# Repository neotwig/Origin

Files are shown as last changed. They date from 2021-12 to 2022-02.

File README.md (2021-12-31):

# Origin

Origin is an open-source, customizable touchscreen HDMI switch with IR remote control.

This project was created by Ryan Black with coding by David Williams.  Documentation written by Ryan Black.

An annoucement video with a demonstration of a 25 port unit is [posted here](https://youtu.be/hIJCa2q1oEo).

Special thanks to Bob from [RetroRGB](https://www.retrorgb.com/) for his help in advertising the first and second generation units, allowing me to recoup some of my development costs.

## Features

* Can be built in 5, 9, 13 or 25 port configurations (17 or 21 ports are possible, but not yet implemented)
* 3.2" or 7" touchscreen display with brightness and auto-dimming / auto-off settings
* Infrared remote control, user-programmable to work with most any IR remote control
* User-configurable input names and color scheme
* Uses 1 to 6 HDMI switchboards internally.  Origin is designed to power off any switchboards not currently needed to conserve power.  Only 1 or 2 switchboards are powered at any given time.

## License

I am releasing the source code and build instructions under the MIT license.  You are free to use any of it however you would like.  If you profit from my work, please consider sending a little something my way since I did invest quite a bit of time and money into this project.

There is no warranty of any kind, and it is up to you to make sure you build and use the device SAFELY.  If you plug 25 consoles into a lightweight extension cord and burn down your house, that is on you!  If you don't know how to work with electronic devices and electricity safely, this project is not for you.  Please game responsibly.

## Limitations

* I am not selling these devices.  I have a few extras I may sell to recover some of my development costs, but once they're gone, they're gone.  Total parts cost is high and the build is time consuming, so I cannot make these at a price most people would be willing to pay.  Current cost for PARTS ONLY for a 3.2" 9 port model is $250, and a 7" 25 port model is $500.
* I am not providing support for these devices.  Sorry, I am very busy and don't have the time to provide free technical support.
* I am NOT an expert at any of this.  I know just enough to get this working but this is a hobby, not a career.  There are probably better ways to do the electronics, the coding, and the 3D modeling for the case.  I welcome any and all improvements to the project.
* As of this writing, the 3.2" display models support 5, 9, and 13 port configurations.  The 7" display models only support 25 port configurations.
* The HDMI switchboards used internally DO support auto-switching of devices, but Origin does NOT support this as a whole.  Auto-switching will occur within a 5 port switchboard, but not for the rest of Origin.  Example: Ports 6-10 on a 25 port model are on the same physical switch board.  If I am using device #6 and turn it off, and device #10 is powered on, the switchboard will auto-select device #10.  However, if I then turn on device #2 and turn off device #10, it will NOT switch to device #2 since that is a different switchboard.

## Feature Additions

At this point in time, I do not plan to add any more features.  There are other things I would like to see added, but I am leaving this to the community.  Some ideas include:
* Protections against the user selecting conflicting colors, such as black text on a black background
* Wi-Fi / Ethernet / Bluetooth connectivity
* Web interface and/or phone and tablet apps to control and configure Origin
* The ability to control power for connected systems, such that pressing the NES button turns on your NES console via a smart outlet
* Support for pictures instead of just text, so that the user can touch an image of a console
* Full-screen display of the selected input for easier reading from across a room, especially when changing inputs via remote control

I am not going to claim that the GUI is perfect, but I did invest extra time in making it as close as I could.  I am certainly open to improvements, but fair warning that I am picky about this.  For example, Nextion does not natively allow for centering of multi-line text on buttons.  It "centers" the text as a block, with all lines left-justified based on the longest line.  I find this to be inexcusable, so I wrote extra code to implement proper multi-line centering with hotspots instead.  This does make the code more complex, but I think the user interface looks substantially better as a result.

## Hardware Build Video

I've created a [build video](https://youtu.be/xENX4zxrqHY) explaining the process from beginning to end, excluding the 3D printing of the enclosure.  The video is for a 5 port model, but the process is nearly identical for any port configuration.  The video is 1 hour and 42 minutes long.  I sped up some of the more tedious and repetitive tasks to shorten it as much as I could.

When building a device, you'll need to place a FAT32 formatted Micro SD card in the standalone internal SD card reader (NOT the one on the Nextion display).  You can pre-populate it with one of the provided sample preference files if you want, but if one doesn't exist then the software will generate a new one for you.

Note that the pin definitions are specified in the file "libraries\Origin\OriginConfig.h", so you may want to reference that for hooking up the wiring.

The commercial HDMI switchboards I've used are all internally branded as "ASK Technology" models "HDSW0015M1_1V3" or "HDSW0015M1_1V4".  Other models may not work, or may require significant modifications to the board, wiring, code, or enclosure design.

## Software Build Instructions

Requirements
* [Arduino IDE](https://www.arduino.cc/en/software) (developed with version 1.8.13)
* [Nextion Editor](https://nextion.tech/nextion-editor/) (developed with version 1.63.3)

Place the contents of the "libaries" folder inside your Arduino libraries folder.  On Windows, this is in your Documents library under Arduino\libraries.

Edit the file "OriginConfig.h" to specify the number of connected HDMI switches.  A 9 port Origin uses 2 switchboards, so set NUM_SWITCHES = 2.  A 25 port Origin uses 6 physical switchboards, so set NUM_SWITCHES = 6.

Connect the Arduino Mega 2650 to your computer via USB.  Select the Arduino Mega 2560 board in the Tools menu under the Board submenu, and choose the port your Arduino is connected to.  If you've already removed the Arduino fuse (per the build instructions) and/or connected the Arduino to other Origin components such as HDMI switchboards and a touchscreen, you must supply external power to the Origin box in order to program the Arduino.

The Nextion display is programmed with a Micro SD card.  If you have the same Nextion display model that I used, you can simply copy the appropriate .tft file to a FAT32 formatted Micro SD card.  If you are using a different model, you have to export a TFT file using the Nextion Editor software.  To program the Nextion, first turn Origin off.  Insert the Micro SD card into the slot on the bottom of Origin.  Then power Origin on, and you should see the display install the new code.  Once it reports that it is complete, you may power off Origin and remove the Micro SD card.

## History

This is the third generation of the Origin HDMI switch, but the first two were not publicly released.  I developed the first two versions entirely by myself, which proved to be quite a challenge!  I selected the name "Origin" due to the purpose of the device.  My goal was to have a single point to select any video game console or multimedia device, rather than having to change inputs on the TV and also on a variety of switchboxes.  Hence, the "Origin" of all video signals in your entertainment setup would be this switchbox, and your TV's input selection never has to change.

I started by making a 17 port version based on HDMI 1.3b switches.  It was a learning project, to push the limits of my electronics, coding, and 3D modeling skills.  All of these things were purely hobbies that I learned by watching YouTube videos, reading documentation and experimenting on sacrificial electronics.  I originally only made one Origin device for my personal use.  After successful completion of the project, I decided to make and sell two more.  Unfortunately they were expensive to make, time consuming to build, and would not be feasible to sell for profit.

The second generation was also a 17 port version, and it was based on HDMI 1.4 switches.  The goal of the second version was to reduce the cost of materials and possibly produce small batches for sale.  Unfortunately the cheaper components led to compatibility issues with some systems such as Hi-Def NES and UltraHDMI N64 modded consoles.  The design of the cheaper HDMI switches allowed for direct control over input selection which was an advantage over both the first and third iterations of Origin, but the compatibility issues and lack of support for HDMI 2.0 made it less desirable.  Seven of these models were made and sold, but despite the cheaper materials they were still not profitable, partly due to the compatibility issues.

I set forth to develop a third generation Origin device.  By this time my game console collection had grown beyond the 17 ports of the original version, and HDMI 2.0 support was becoming more important.  Since the first two models were not profitable, and the parts to support HDMI 2.0 were even more expensive, I decided to throw profitability out the window and simply develop the best switch possible, regardless of cost, with the intention of open-sourcing the device rather than trying to sell it.  I purchased and tested numerous HDMI switches and cables.  I had to tear each HDMI switch apart to determine how readily it could be controlled by an Arduino.  I focused on models that are widely available since development takes a long time and there's no point in open-sourcing something if the hardware is discontinued by the time the project is complete.  Eventually I landed on a set of parts that provided the best compatibility, modability, and availability.  The list of parts is included in this release, though availability may change as time goes on.

I recruited my friend David to help set with the coding part of the new Origin project.  Unlike myself, he does coding professionally and has a much better understanding of how to arrange things.  Don't blame him for any mess you might find in the code though, as I did contribute a fair amount with my duct tape and bubblegum "just get it done" coding skills.  :)

Traditional Arduino-compatible touchscreen displays are very slow, and I knew that something better would be needed for anything larger than 17 ports.  I landed on a much more expensive, but much more powerful Nextion display.  These displays have their own processor and their own programming environment and language.  It presented another learning curve, but I think it was the right choice.  A Nextion expert could significantly improve the way it's implemented, but David and I came up with a reasonably fast and user-friendly interface.  It's our first Nextion project, so improvements are welcome!

This project has taken approximately 3 years to complete as a hobby project, not a full-time endeavor.  It has been an expensive undertaking, with the need for 3D printing hardware, filament, soldering tools and supplies, and a fair amount of HDMI switches which were sacrificed to find the best configuration.

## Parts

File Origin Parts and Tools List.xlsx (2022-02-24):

Type | Description with link as of 12/2021 | Approx. cost as of 12/2021 | Notes
Part | Arduino MEGA R3 Board ATmega 2560 (https://www.amazon.com/gp/product/B01H4ZLZLQ) | $18
Part | ViewHD 5 port HDMI 2.0 5x1 Switch UHD5X1 (https://www.amazon.com/gp/product/B07J6GJ448) | $33 each
Part | AwakeLion 5 port HDMI 2.0 Switch (https://www.amazon.com/Switch-Awakelion-Premium-Switcher-Support/dp/B06WV5YJ6H) | $40 each
Part | HDMI Cable 4K Ultra HD 1 Foot (3 Pack) (https://www.amazon.com/gp/product/B074HQQWD7) | $15 for 3 | need x-1 where x is number of switch boards
Part | HDMI Cable 4K Ultra HD 1 Foot (10 Pack) (https://www.amazon.com/gp/product/B074HGW2FC) | $25 for 10 | need x-1 where x is number of switch boards
Part | Nextion NX4024T032 Display - 3.2" (https://www.amazon.com/dp/B08535GC8J) | $37 | CASE IS NOT NEEDED, but Amazon is out of stock of just the display as of 2/23/22
Part | Nextion NX8048K070 Display - 7" (https://www.amazon.com/gp/product/B079177F98) | $113
Part | AC/DC Wall Mount Adapter 5V 20W (https://www.digikey.com/en/products/detail/cui-inc/SWI25-5-N-P5/7070092) | $18 + shipping
Part | IR Receiver TSOP34438 (https://www.digikey.com/en/products/detail/vishay-semiconductor-opto-division/TSOP34438/4074442) | $1.50 + shipping | currently out of stock, untested possible replacement TSOP34438SS1F
Part | 3.3V-5V 4 Channels Logic Level Converter (https://www.amazon.com/gp/product/B074M8TM81) | $9 for 10 | need 1 per switch board
Part | Micro SD Card Reader (https://www.amazon.com/HiLetgo-Adater-Interface-Conversion-Arduino/dp/B07BJ2P6X6) | $7 for 5 | need 1
Part | 5.5mm x 2.1mm DC Power Jack Panel Mount (https://www.amazon.com/gp/product/B073TS9H3S) | $9 for 20 | need 1
Part | SPST Snap in Mini Boat Rocker Switch (https://www.amazon.com/gp/product/B018FHB0H6) | $6 for 12 | need 1
Part | BusBoard (https://www.amazon.com/gp/product/B00PX52C7Q) | $10 for 8 | need 1
Part | 24 AWG Gauge Solid Hook Up Wire Kit (https://www.ebay.com/itm/322071452367) | $34 for 25 feet | need approximately 2 ft per switch board
Part | Heatshrink Tubing (https://www.amazon.com/gp/product/B073R69KNB) | $9 for a large pack | need only a tiny amount
Part | Rubber Bumpers Self Adhesive Large (https://www.amazon.com/gp/product/B01MR94CHS) | $11 for 20 | need 4
Part | Chemtronics Desoldering Braid (50 ft) Chem-Wik (https://www.amazon.com/gp/product/B0019V5MAC) | $20 for 50 ft | need only a few inches
Part | Steel Phillips Rounded Head Thread-Forming Screws for Plastic #4, 1/4" - McMaster-Carr Part 90380A106 (https://www.mcmaster.com/thread-forming-for-plastic/for-use-in~plastic/steel-phillips-rounded-head-thread-forming-screws-for-plastic/) | $9 + shipping for 100 | need qty 2 per switch board, qty 4 for 7" screen
Part | Steel Phillips Rounded Head Thread-Forming Screws for Plastic #4 - 3/8" - McMaster-Carr Part 90380A108 (https://www.mcmaster.com/thread-forming-for-plastic/for-use-in~plastic/steel-phillips-rounded-head-thread-forming-screws-for-plastic/) | $9 + shipping for 100 | need qty 6 for bottom, 4 for front panel, 2 for Arduino, 2 for power dist board
Part | HATCHBOX ABS 3D Printer Filament 1.75 mm Black (https://www.amazon.com/HATCHBOX-3D-Filament-Dimensional-Accuracy/dp/B00J0H8EWA) | $22 per spool | can make approx 3 total cases per spool
Part | HATCHBOX ABS 3D Printer Filament 1.75 mm White (https://www.amazon.com/HATCHBOX-3D-Filament-Dimensional-Accuracy/dp/B00J0H6NNM) | $22 per spool | need fairly negligible amount
Part | HATCHBOX ABS 3D Printer Filament 1.75 mm Green (https://www.amazon.com/HATCHBOX-3D-Filament-Dimensional-Accuracy/dp/B00J0HC4QC) | $22 per spool | need fairly negligible amount
Part | HATCHBOX ABS 3D Printer Filament 1.75 mm Red (https://www.amazon.com/HATCHBOX-3D-Filament-Dimensional-Accuracy/dp/B00J0HB1YI) | $23 per spool | need fairly negligible amount
Tool | Hakko FX888D Soldering Station (https://www.amazon.com/gp/product/B00C2BHTBI) | $145
Tool | Hakko FR301-03/P Desoldering Tool (https://www.amazon.com/American-HAKKO-Products-FR301-03-Desoldering/dp/B07BFVFMS9) | $269
Tool | Hakko 599B-02 Wire-type soldering iron tip cleaner (https://www.amazon.com/gp/product/B00FZPGDLA) | $11
Tool | Hakko CHP-170 Micro Cutter (https://www.amazon.com/gp/product/B00FZPDG1K) | $8
Tool | Mini Heat Gun (https://www.amazon.com/gp/product/B073RK2M2Y) | $13
Tool | Quick 861DW Hot Air Rework Station (https://www.amazon.com/Quick-861DW-Digital-Station-Display/dp/B00EID23J6) | $312
Tool | Xcelite NN7776VN Long Needle Nose Plier (https://www.amazon.com/Xcelite-NN7776VN-Long-Nose-Plier/dp/B074NKR8PT) | $21
Tool | Prusa i3 MK3S+ 3D Printer (https://www.prusa3d.com/product/original-prusa-i3-mk3s-3d-printer-5/) | $1039
Tool | Prusa i3 MMU2S upgrade kit (https://www.prusa3d.com/product/original-prusa-i3-mmu2s-upgrade-kit-for-mk2-5-mk3s-org/) | $299

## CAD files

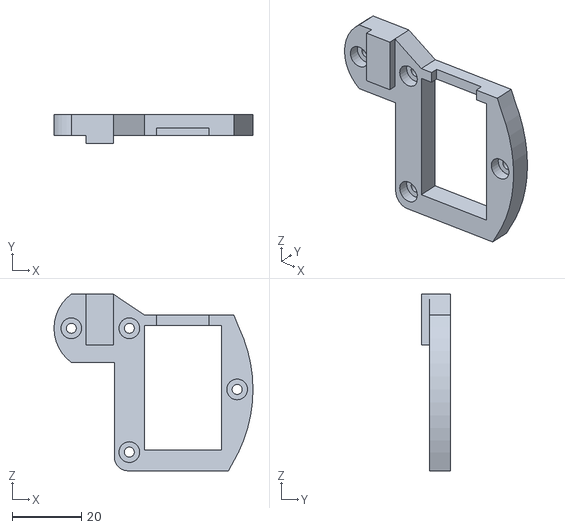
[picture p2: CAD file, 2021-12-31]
Enclosure Design/3.2 inch display/front bracket.stl
57.5 x 8.30 x 51.0

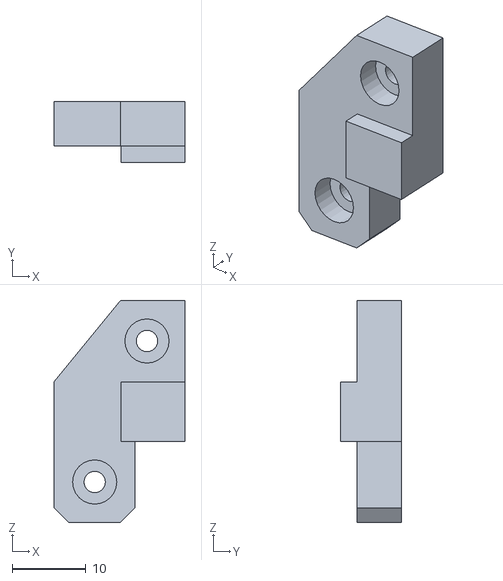
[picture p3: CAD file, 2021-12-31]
Enclosure Design/7.0 inch display/IR cover plate.stl
17.7 x 8.30 x 30.2

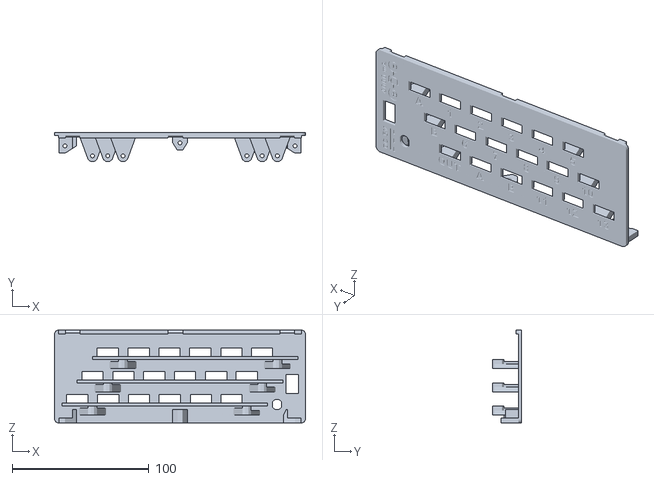
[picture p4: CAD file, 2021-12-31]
Enclosure Design/3.2 inch display/back 3 swx black.stl
183.7 x 21.4 x 68.0

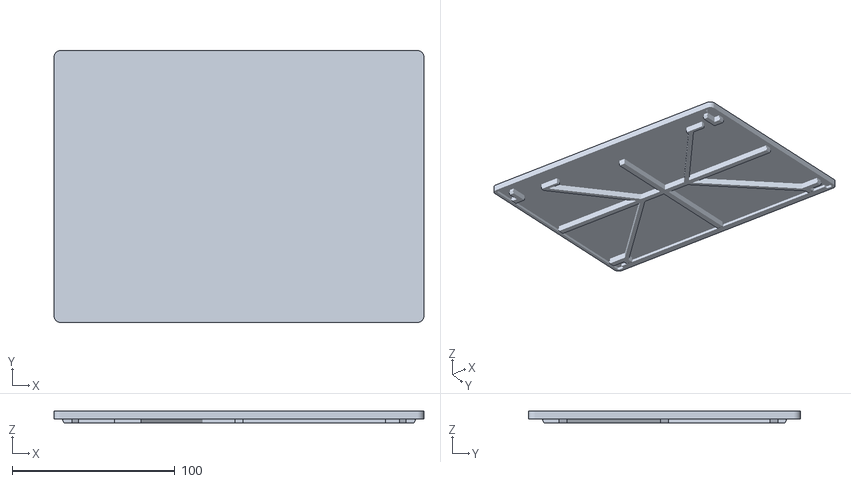
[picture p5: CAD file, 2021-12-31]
Enclosure Design/7.0 inch display/top panel.stl
227.0 x 166.7 x 7.50

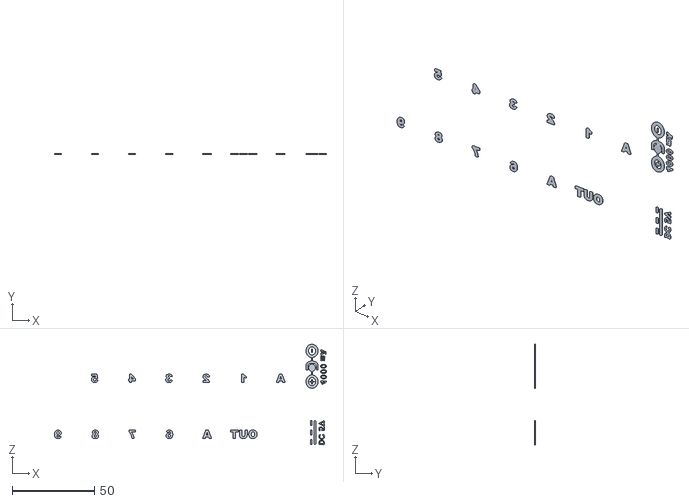
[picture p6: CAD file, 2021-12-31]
Enclosure Design/3.2 inch display/back 2 swx white.stl
165.1 x 0.653 x 61.1

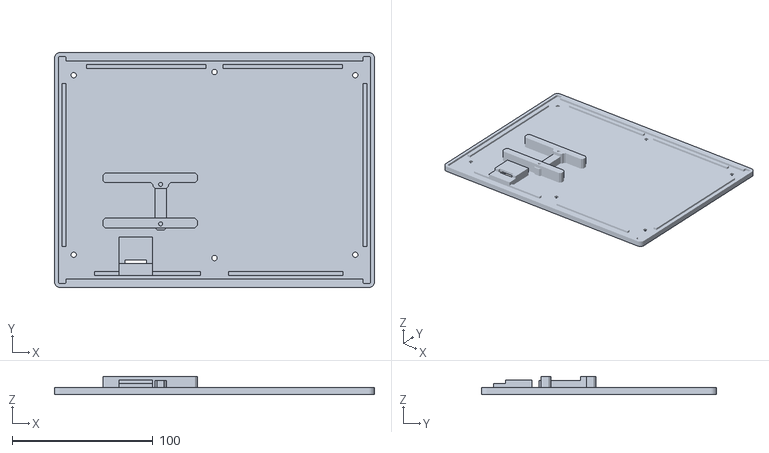
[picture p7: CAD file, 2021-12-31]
Enclosure Design/7.0 inch display/bottom panel.stl
227.0 x 166.7 x 13.0

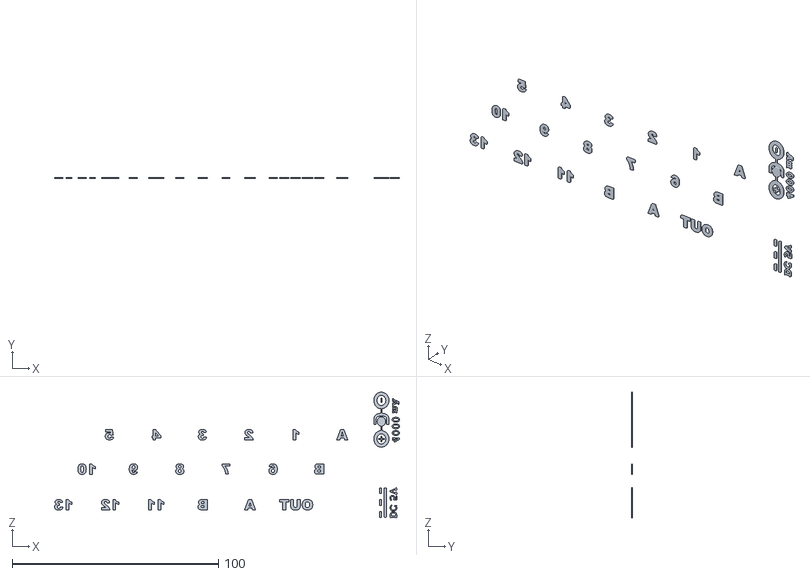
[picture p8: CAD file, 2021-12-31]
Enclosure Design/3.2 inch display/back 3 swx white.stl
167.3 x 0.655 x 61.1

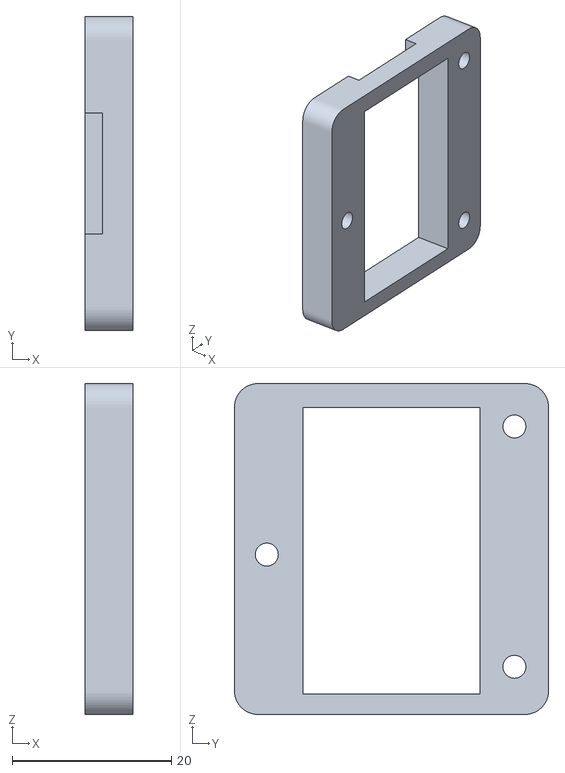
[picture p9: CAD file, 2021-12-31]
Enclosure Design/7.0 inch display/SD card cover plate.stl
6.05 x 39.5 x 41.6

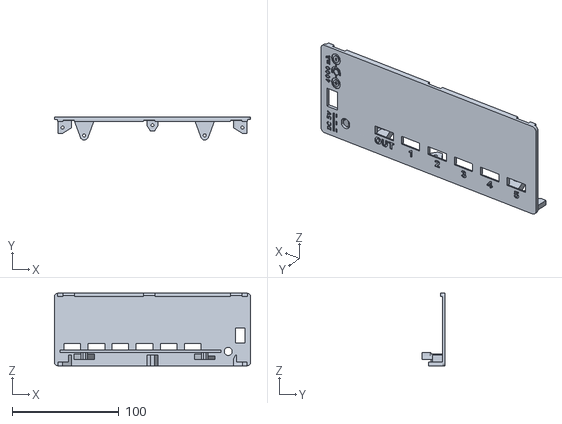
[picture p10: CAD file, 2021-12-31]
Enclosure Design/3.2 inch display/back 1 swx black.stl
183.7 x 21.4 x 68.0

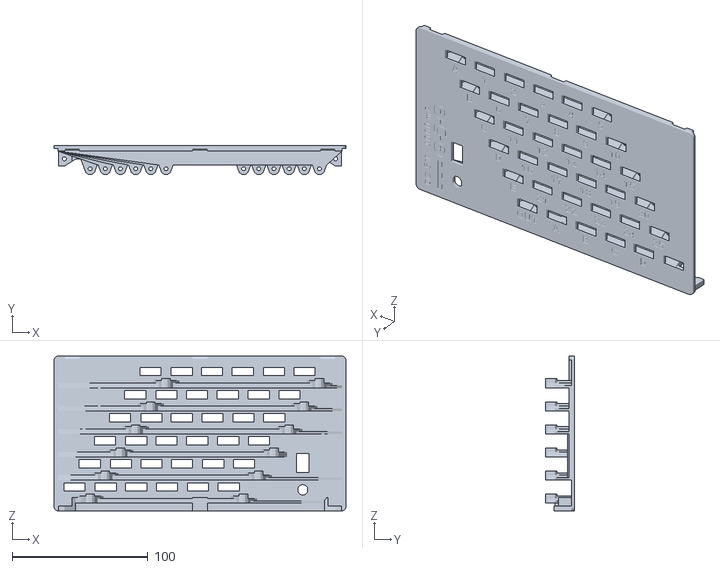
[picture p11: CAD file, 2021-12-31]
Enclosure Design/7.0 inch display/back panel black.stl
215.0 x 21.4 x 114.0

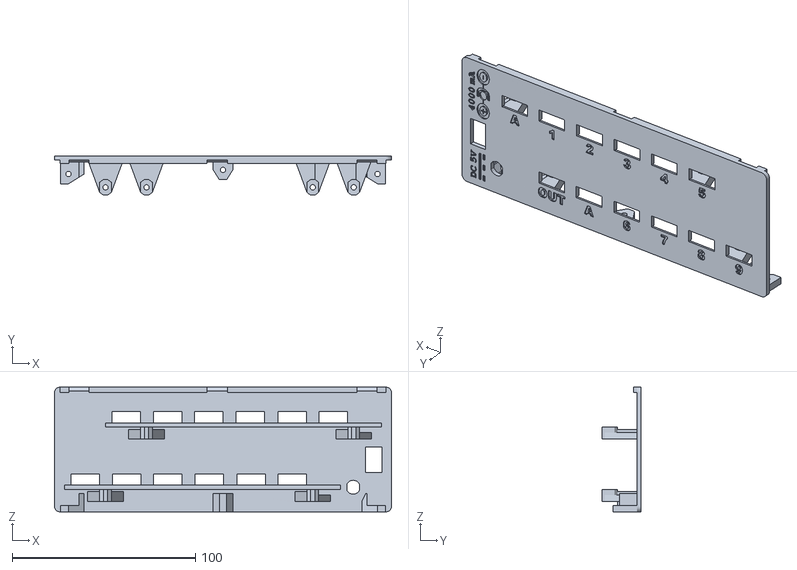
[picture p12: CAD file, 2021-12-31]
Enclosure Design/3.2 inch display/back 2 swx black.stl
183.7 x 21.4 x 68.0

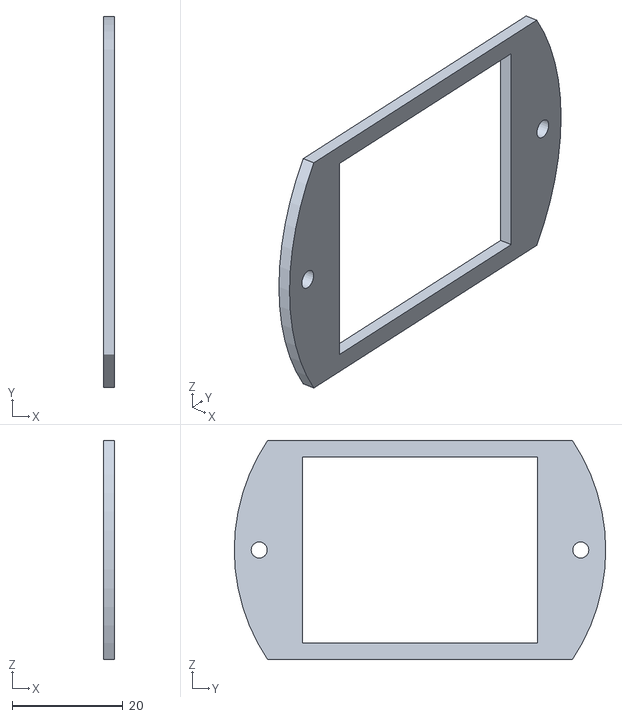
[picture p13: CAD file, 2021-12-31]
Enclosure Design/7.0 inch display/power board cover plate.stl
2.05 x 67.0 x 39.5

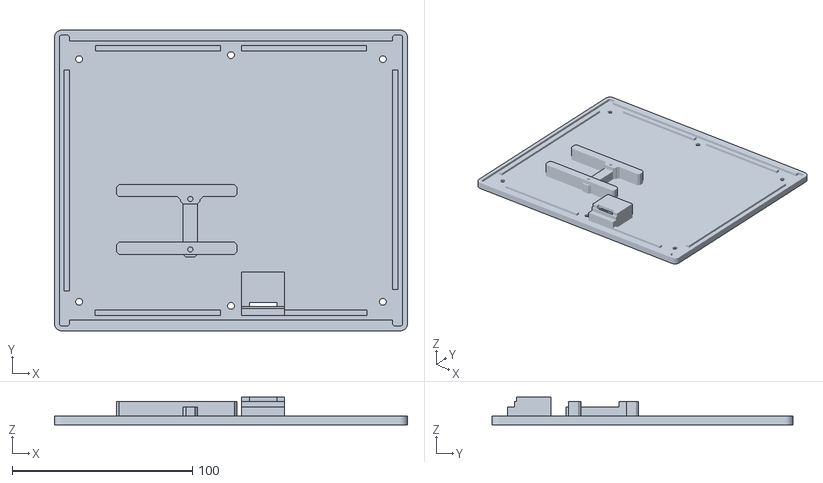
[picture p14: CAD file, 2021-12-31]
Enclosure Design/3.2 inch display/bottom panel.stl
195.8 x 166.7 x 15.4

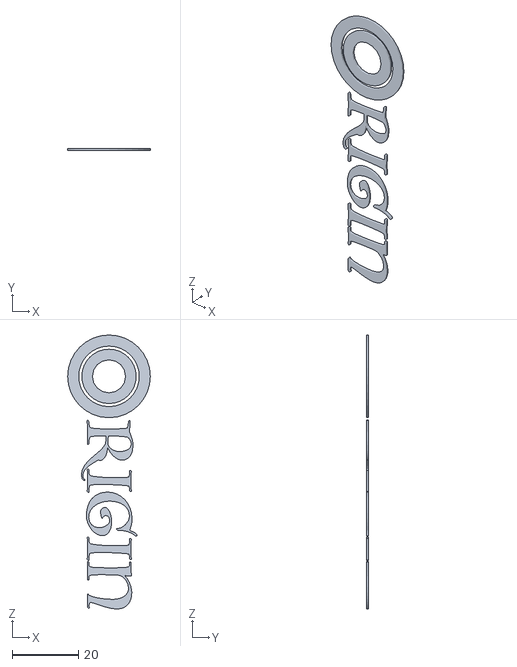
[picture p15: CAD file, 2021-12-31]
Enclosure Design/7.0 inch display/front panel red.stl
25.0 x 0.65 x 82.7

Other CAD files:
Enclosure Design/3.2 inch display/front white.stl
Enclosure Design/7.0 inch display/back panel white.stl
Enclosure Design/3.2 inch display/top panel.stl
Enclosure Design/7.0 inch display/front panel black.stl
Enclosure Design/3.2 inch display/back 1 swx white.stl
Enclosure Design/3.2 inch display/front black.stl
Enclosure Design/3.2 inch display/front green.stl
Enclosure Design/3.2 inch display/front red.stl
Enclosure Design/3.2 inch display/left panel.stl
Enclosure Design/3.2 inch display/right bracket.stl
Enclosure Design/3.2 inch display/right panel.stl
Enclosure Design/3.2 inch display/whole case 1 swx.skp
Enclosure Design/7.0 inch display/left panel.stl
Enclosure Design/7.0 inch display/right panel.stl

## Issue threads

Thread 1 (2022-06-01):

Fifth contact on switch PCB

sargunv, 2022-06-01:
Hi, I’m working on modding the same commercial HDMI switch you used for this project, the HDSW0015M1_1V4. Like you, I found the five pads on the PCB, two of which are wired to the buttons and the next two ground and 3.3V.

Unfortunately, I haven’t been able to figure out what the fifth pad in that row is for. Have you found what it’s used for?

My project is to build a mod that allows me to control the HDSW0015M1_1V4 over a serial connection, very similar to your Origin but without the extra switches and without the touch screen, just serial control for automation.

neotwig, 2022-06-01:
I never figured out what it was for, but I didn't need it for my project. I just used that connection for additional physical support of the level converter, but it isn't connected to the Arduino. If you're able to identify what it does, please share.

sargunv, 2022-06-01:
Last night I did use a multimeter to find it connects to the big IC in the middle just like the others, specifically the eighth pin from the left on the side facing the buttons.

Multimeter shows 0V on that pin whatever I do. Perhaps an input of some kind?

Next step would be removing the heat sink to try to see what that IC is and find the datasheet to identify the pins.

I also don't need this pad for my project, but am curious what it's for if they went to the trouble of creating an easy access pad for it. I'm also just a hobbyist, learning as I go with this project 🤷‍♂️

sargunv, 2022-06-01:
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

sargunv, 2022-06-04:
I can't find any pins on the datasheet for direct input switching, that functionality must only be exposed directly to the included microcontroller.

However, we _should_ be able to implement direct input switching anyway. Since the remote has input buttons 1-5 as well as direct on/off buttons, replacing the IR receiver with our own microcontroller should give us to ability to tell it to do those same things.

I haven't looked too deeply into doing this yet, but I did take a look at the voltages on that line and found it idles high, so I think we'd need to disconnect the actual IR receiver to properly simulate the signal from its pads. Going to attempt it once I've finished my prototype with just the straightforward I/O (the test pads and LEDs, like your project).

sargunv, 2022-06-04:
Full pinout here might be useful to you or anyone who comes across this thread.

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

sargunv, 2022-06-04:
Confirmed I can fake the IR commands from my Arduino Pro Mini. See the example code below.

I used [this tester](https://www.amazon.com/gp/product/B08K3BGKXC/) to grab the NEC signal codes, then [IrScrutinizer](https://github.com/bengtmartensson/IrScrutinizer) to get the unmodulated sequence, and finally the [Infrared4Arduino](https://github.com/bengtmartensson/Infrared4Arduino) library to send the sequence to the board.

```c++
#include <Nec1Renderer.h>
#include <IrSenderNonMod.h>

// pin connected to the leftmost pad that used to have the IR receiver
const int pinNec = 2;

// pin connected to the power LED
const int pinIdle = 8;

// generated with IrScrutinizer
// NEC encoding, device=1, function=31
const microseconds_t offData[] = {
  9024,4512,564,1692,564,564,564,564,564,564,564,564,564,564,564,564,564,564,564,
  564,564,1692,564,1692,564,1692,564,1692,564,1692,564,1692,564,1692,564,1692,564,
  1692,564,1692,564,1692,564,1692,564,564,564,564,564,564,564,564,564,564,564,564,
  564,564,564,564,564,1692,564,1692,564,1692,564,39756
};
const IrSequence offSeq(offData, sizeof(offData) / sizeof(microseconds_t));

// generated with IrScrutinizer
// NEC encoding, device=1, function=92
const microseconds_t onData[] = {
  9024,4512,564,1692,564,564,564,564,564,564,564,564,564,564,564,564,564,564,564,
  564,564,1692,564,1692,564,1692,564,1692,564,1692,564,1692,564,1692,564,564,564,
  564,564,1692,564,1692,564,1692,564,564,564,1692,564,564,564,1692,564,1692,564,
  564,564,564,564,564,564,1692,564,564,564,1692,564,39756
};
const IrSequence onSeq(onData, sizeof(onData) / sizeof(microseconds_t));

const IrSenderNonMod sender(pinNec, true);

void setup() {
  pinMode(pinNec, OUTPUT);
  pinMode(pinIdle, INPUT);
}

void loop() {
  auto idleVal = !digitalRead(pinIdle);

  if (idleVal) {
    sender.sendNonModulated(onSeq);
  } else {
    sender.sendNonModulated(offSeq);
  }

  delay(1000);
}
```

Here's the full list of the remote's functions I got from my tester. Device = 1 for all of them.

```
off -> 31
on -> 92
input 1 -> 27
input 2 -> 30
input 3 -> 13
input 4 -> 18
input 5 -> 16
next input -> 12
prev input -> 5
```

With this, I prob won't even bother hooking up the button on my final prototype; faking the IR signal does it all.

neotwig, 2022-06-06:
That is really awesome work, and thanks for the detailed explanation!  I bet this could be used to simplify the build for Origin and probably speed up input switching as well.

sargunv, 2022-06-07:
Glad it's helpful!

I managed to get the IR signal code to be much, much simpler using [a different IR library](https://github.com/Arduino-IRremote/Arduino-IRremote) and its `USE_NO_SEND_PWM` build flag.

https://github.com/sargunv/hdmi-switch-controller/blob/5250a682ed24b1df7fe1f89b9b76943275b6d30e/src/main.cpp

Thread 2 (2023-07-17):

Have you heard of anyone getting this to work with other revisions of the HDMI boards.

Slovlis, 2023-07-17:
I was super impressed with this project and had been wanting to try it for a while. Unfortunately, when I purchased the Awakelion HDMI switch from the parts list it's a different hardware revision. Still by ASK Technology, but version HDSW0032M1_1v0.
It does have the through holes to solder the headers for 3.3v and ground but when I probed the others it doesn't look like any go to the power and input switches. Just curious if you had heard of anyone using one of the other revisions, or do you think I could tap into the switches directly with some additional wiring from the level converter?
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

neotwig, 2023-07-17:
Ah, that's a bummer!  I was unaware that they have changed the boards internally.  It should be possible to wire the level converter directly to the appropriate leg of the power and switch input buttons.  Provided there aren't any other major changes I would think that should work without too much trouble.  You might not have as convenient of a place to mount the level converter PCB, but functionally it should be the same.

However, before you go to the trouble of mapping that all out, I would suggest just hooking two of these switches up together externally (in their original cases without modification) with a jumper HDMI cable going from the output of one to an input of another, and try a few different devices on various HDMI ports.  Particularly focus on ones on the second switch in the chain, to make sure that the HDMI signal travels through both switches to your TV without causing problems.  Ports RX4 and RX3 on your first pic are the most likely to have issues since they go through another chip, so be sure to test the "worst case scenario" of a device connected to RX4 on one switch with the output of that switch going to RX4 of the second switch before going to your TV.  I did find a few switches and cables that wouldn't properly transmit the signal, and if they can't do it on their own then there isn't any point in wiring them up.  If it doesn't work, try different cables first before swapping switch boards.  Thicker cables tend to work better between switches and between the last switch and the TV.

sargunv, 2024-05-16:
It's a different approach, but [my similar project](https://github.com/sargunv/hdmi-switch-controller) replaces the IR receiver and sends signals over that line simulating the IR codes to trigger the various inputs. The new board might have new IR codes, not sure, but the general strategy should still work.

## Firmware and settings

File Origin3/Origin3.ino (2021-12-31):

//////////////////////////////////////////////////////////////////////////////////////////////////////
//////////////////////   Origin 5, 9, 13, 17, 21, or 25 port HDMI 2.0 Switch   ///////////////////////
//////////////////////////////////////////////////////////////////////////////////////////////////////

#include <Arduino.h>
#include <OriginConfig.h>
#include <Origin.h>
#include <SPI.h>       // SPI = Serial Peripheral Interface.  Required for SD cards, among other things.
#include <SD.h>        // SD card reader
#include <Nextion.h>   // Nextion Display
#include <NextionHelper.h>
#include <SwitchBoard.h>

//////////////////////////////////////////////////////////////////////////////////////////////////////
// NOTE: NexHardware.h has default timeout values of 100 ms.  These need to be extended to allow some
// operations to complete without errors.  3000 ms is recommended.  Lower values would probably work
// but have not been tested.  If the default 100 ms value is unmodified, save and load operations will
// produce unexpected results, such as shifting input labels or leaving some/all input labels blank.
//////////////////////////////////////////////////////////////////////////////////////////////////////

Origin origin;
NextionHelper nexHelper;
int lastDisplayedInput = 0;
int targetInput = 0;

void setup()
{
  // debugging code is turned on/off in NexConfig.h
  
	nexInit(); // no debugging code can occur before this, as it initializes serial communications (see NexHardware.cpp)
  
  dbSerialPrintln("Initializing NexHelper library");
  nexHelper.Init();

  // if the Arduino has rebooted (usually due to programming), reset the Nextion also.  102 = Nextion splash screen
  if (nexHelper.getMenuMode() != 102) nexHelper.gotoPage(0);
  
  dbSerialPrintln("Initializing Origin library");
	origin.setupOrigin();
 
  dbSerialPrintln("Reading data from SD card");
	nexHelper.readFromSD(); // if read operation is failing, see note above and extend timeout in NexHardware.h to 3000 ms.
 
	dbSerialPrintln("Setup complete!");
  nexHelper.gotoPage(1); // Nextion display will stay at splash screen until we tell it to go to the grid page (page # 1)
}

// Add the main program code into the continuous loop() function
void loop()
{
  //nexLoop(nexHelper.getNexObjects());

  // process any pending events such as IR codes, and return 0 or a new target input if the IR code indicated an input change
  int newTargetInput = nexHelper.handleEvents();
  if (newTargetInput != 0) {
    targetInput = newTargetInput; // if an IR code indicated an input change, override any existing target input
    nexHelper.setGUIinput(targetInput);
  }

  // targetInput is non-zero if an input change is in process
  if (targetInput != 0) {
    // continue the input change attempt
    targetInput = origin.attemptSetInput(targetInput);
  } else {
    // Handle automatic input switching done by the SwitchBoards themselves.  Update the display to reflect the current input.
    int curInput = origin.getInput();
    if (curInput != lastDisplayedInput)
    {
      lastDisplayedInput = curInput;
      nexHelper.setGUIinput(curInput);
    }
  }
}
